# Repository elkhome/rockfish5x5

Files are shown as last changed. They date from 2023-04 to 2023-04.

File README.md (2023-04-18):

# rockfish5x5
5x5 expandable mechanical keyboard, powered by a Raspberry Pi Pico.

Shared for reference without licence. Not especially original. Feel free to use my design as a reference to design your own board, but I probably wouldn't reccomend trying to build this as is.

Entire design is upside down, and the uploaded revision has not been tested. To acheive the two board layout, the Pico goes on the right board and the solder jumpers are bridged on the left board.

Photo of the keyboard, fully assembled.

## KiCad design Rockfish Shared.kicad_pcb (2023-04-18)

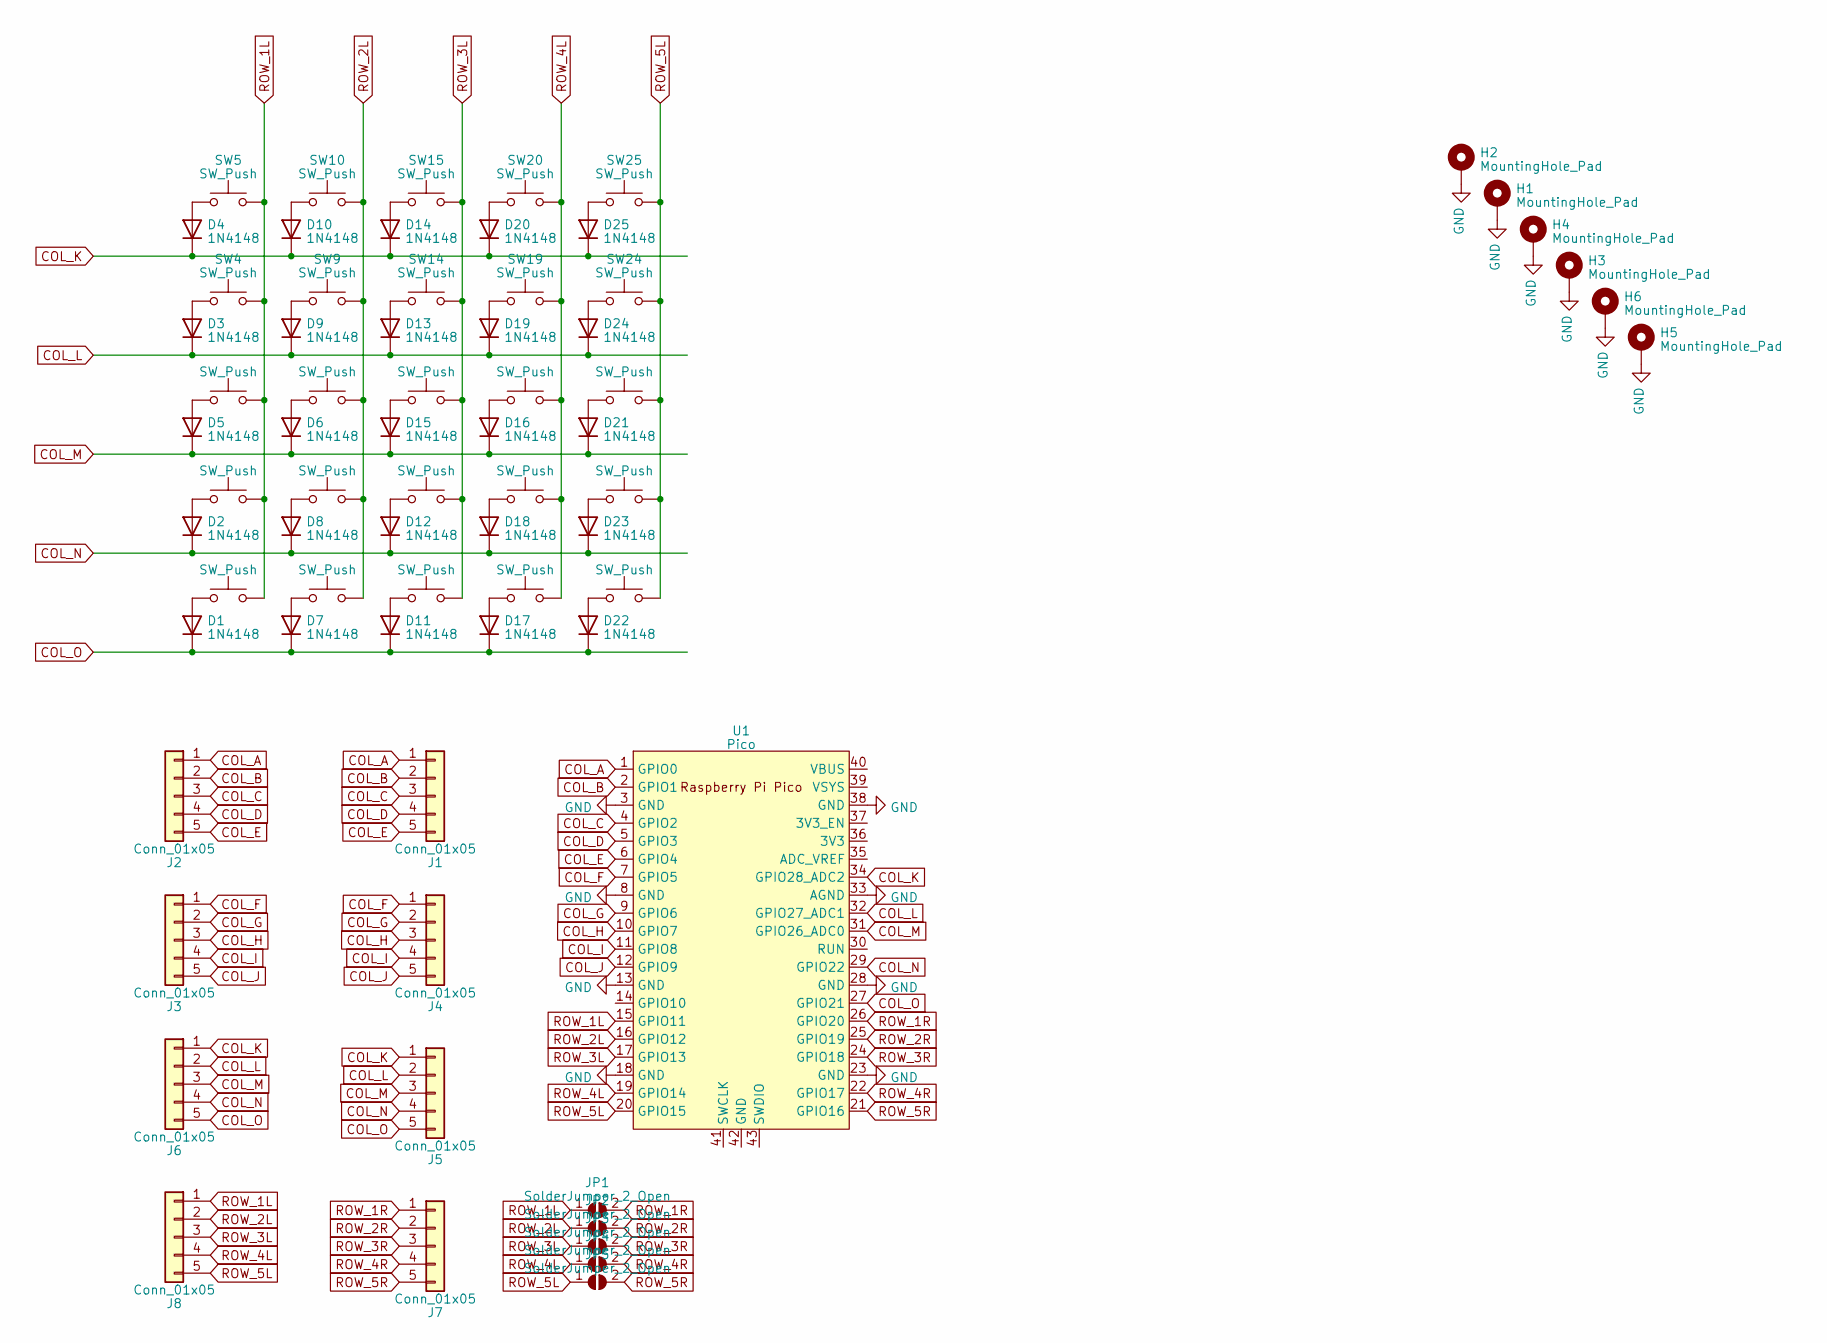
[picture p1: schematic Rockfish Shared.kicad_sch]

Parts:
D1, D2, D3, D4, D5, D6, D7, D8, D9, D10, D11, D12, D13, D14, D15, D16, D17, D18, D19, D20, D21, D22, D23, D24, D25: 1N4148; D_DO-35_SOD27_P7.62mm_Horizontal_no_front_silk
H1, H2, H3, H4, H5, H6: MountingHole_Pad; MountingHole_2.2mm_M2_DIN965_Pad
J1, J2, J3, J4, J5, J6, J7, J8: Conn_01x05; PinHeader_1x05_P2.54mm_Vertical
JP1, JP2, JP3, JP4, JP5: SolderJumper_2_Open; SolderJumper-2_P1.3mm_Open_RoundedPad1.0x1.5mm
SW1, SW2, SW3, SW4, SW5, SW6, SW7, SW8, SW9, SW10, SW11, SW12, SW13, SW14, SW15, SW16, SW17, SW18, SW19, SW20, SW21, SW22, SW23, SW24, SW25: SW_Push; SW_MX_reversible_flip_no_back_silk
U1: Pico; RPi_Pico_SMD_TH

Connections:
COL_A: J1.1, J2.1, U1.1 (GPIO0)
COL_B: J1.2, J2.2, U1.2 (GPIO1)
COL_C: J1.3, J2.3, U1.4 (GPIO2)
COL_D: J1.4, J2.4, U1.5 (GPIO3)
COL_E: J1.5, J2.5, U1.6 (GPIO4)
COL_F: J3.1, J4.1, U1.7 (GPIO5)
COL_G: J3.2, J4.2, U1.9 (GPIO6)
COL_H: J3.3, J4.3, U1.10 (GPIO7)
COL_I: J3.4, J4.4, U1.11 (GPIO8)
COL_J: J3.5, J4.5, U1.12 (GPIO9)
COL_K: D4.1 (K), D10.1 (K), D14.1 (K), D20.1 (K), D25.1 (K), J5.1, J6.1, U1.34 (GPIO28_ADC2)
COL_L: D3.1 (K), D9.1 (K), D13.1 (K), D19.1 (K), D24.1 (K), J5.2, J6.2, U1.32 (GPIO27_ADC1)
COL_M: D5.1 (K), D6.1 (K), D15.1 (K), D16.1 (K), D21.1 (K), J5.3, J6.3, U1.31 (GPIO26_ADC0)
COL_N: D2.1 (K), D8.1 (K), D12.1 (K), D18.1 (K), D23.1 (K), J5.4, J6.4, U1.29 (GPIO22)
COL_O: D1.1 (K), D7.1 (K), D11.1 (K), D17.1 (K), D22.1 (K), J5.5, J6.5, U1.27 (GPIO21)
GND: H1.1, H2.1, H3.1, H4.1, H5.1, H6.1, U1.3 (GND), U1.8 (GND), U1.13 (GND), U1.18 (GND), U1.23 (GND), U1.28 (GND), U1.33 (AGND), U1.38 (GND)
unnamed: D4.2 (A), SW5.1
unnamed: D3.2 (A), SW4.1
unnamed: D2.2 (A), SW2.1
unnamed: D1.2 (A), SW1.1
unnamed: D5.2 (A), SW3.1
unnamed: D6.2 (A), SW8.1
unnamed: D10.2 (A), SW10.1
unnamed: D9.2 (A), SW9.1
unnamed: D8.2 (A), SW7.1
unnamed: D7.2 (A), SW6.1
unnamed: D14.2 (A), SW15.1
unnamed: D13.2 (A), SW14.1
unnamed: D12.2 (A), SW12.1
unnamed: D11.2 (A), SW11.1
unnamed: D15.2 (A), SW13.1
unnamed: D16.2 (A), SW18.1
unnamed: D20.2 (A), SW20.1
unnamed: D19.2 (A), SW19.1
unnamed: D18.2 (A), SW17.1
unnamed: D17.2 (A), SW16.1
unnamed: D21.2 (A), SW23.1
unnamed: D25.2 (A), SW25.1
unnamed: D24.2 (A), SW24.1
unnamed: D23.2 (A), SW22.1
unnamed: D22.2 (A), SW21.1
ROW_1L: J8.1, JP1.1 (A), SW1.2, SW2.2, SW3.2, SW4.2, SW5.2, U1.15 (GPIO11)
ROW_1R: J7.1, JP1.2 (B), U1.26 (GPIO20)
ROW_2L: J8.2, JP2.1 (A), SW6.2, SW7.2, SW8.2, SW9.2, SW10.2, U1.16 (GPIO12)
ROW_2R: J7.2, JP2.2 (B), U1.25 (GPIO19)
ROW_3L: J8.3, JP3.1 (A), SW11.2, SW12.2, SW13.2, SW14.2, SW15.2, U1.17 (GPIO13)
ROW_3R: J7.3, JP3.2 (B), U1.24 (GPIO18)
ROW_4L: J8.4, JP4.1 (A), SW16.2, SW17.2, SW18.2, SW19.2, SW20.2, U1.19 (GPIO14)
ROW_4R: J7.4, JP4.2 (B), U1.22 (GPIO17)
ROW_5L: J8.5, JP5.1 (A), SW21.2, SW22.2, SW23.2, SW24.2, SW25.2, U1.20 (GPIO15)
ROW_5R: J7.5, JP5.2 (B), U1.21 (GPIO16)

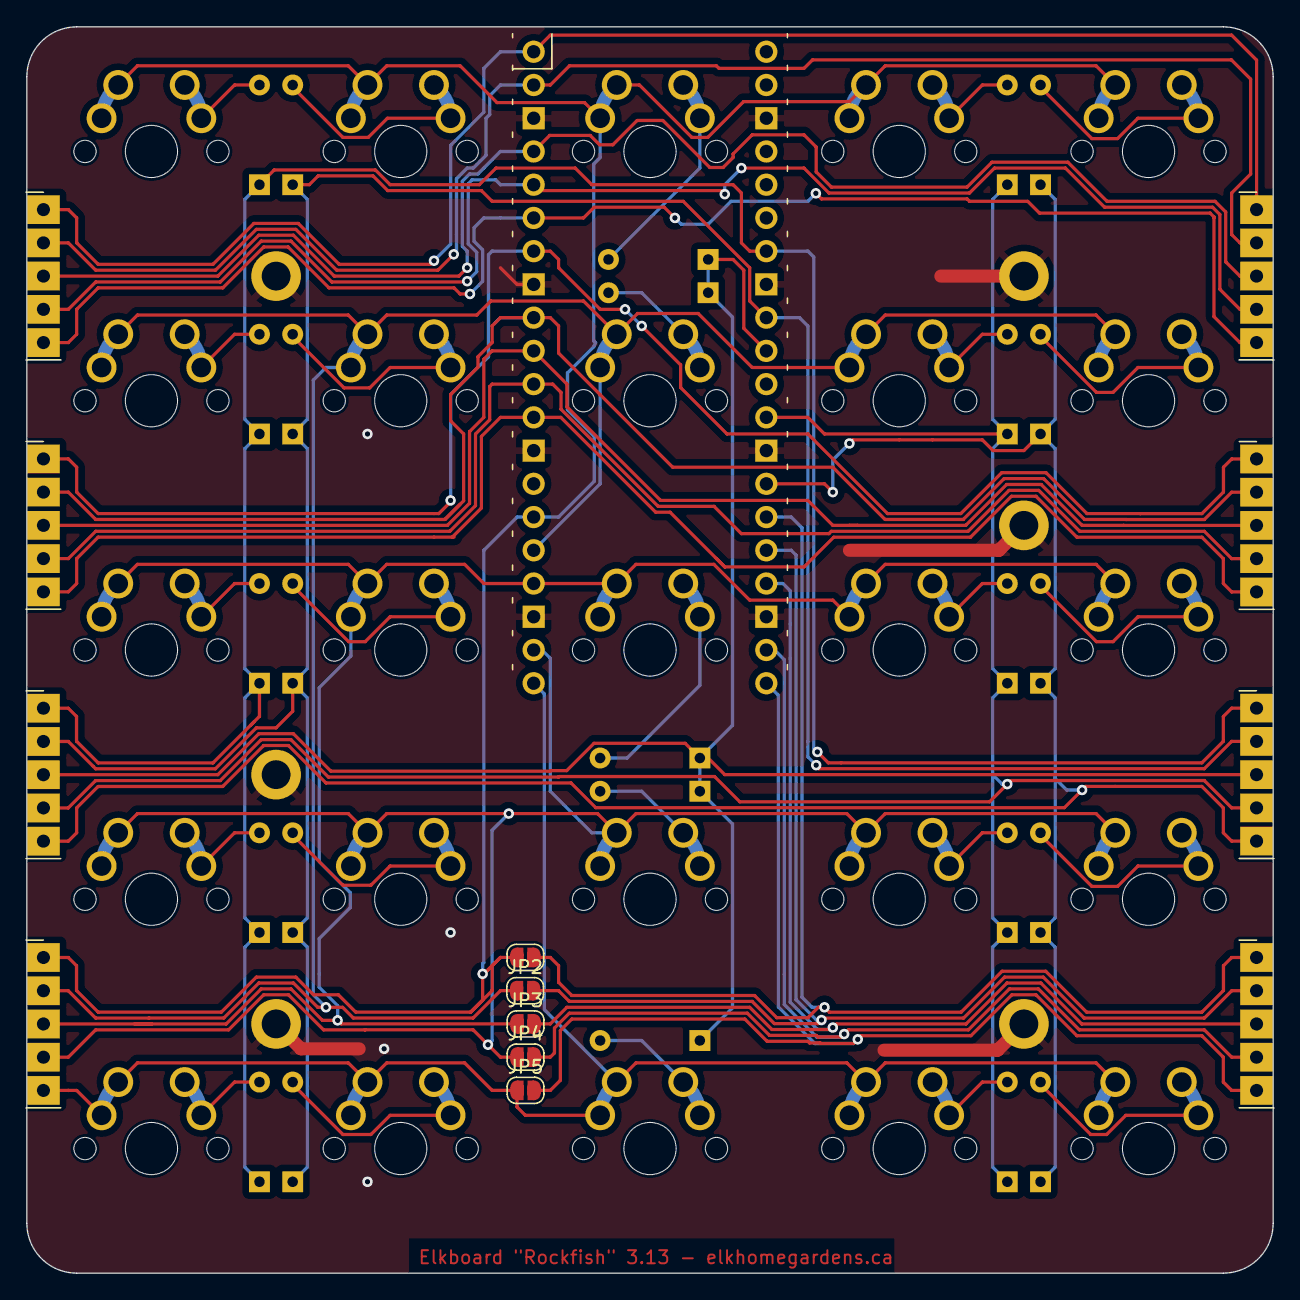
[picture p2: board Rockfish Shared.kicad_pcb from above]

Board: 2 copper layers, 95.3 x 95.3 mm, 70 parts (0 on the bottom side), 51 nets.
